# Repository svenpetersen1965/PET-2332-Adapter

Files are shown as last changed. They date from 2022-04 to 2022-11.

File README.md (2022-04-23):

# PET-2332-Adapter
An EPROM adapter for the 2332 sockets in the Commodore (dynamic) PET and 40xx/80xx.

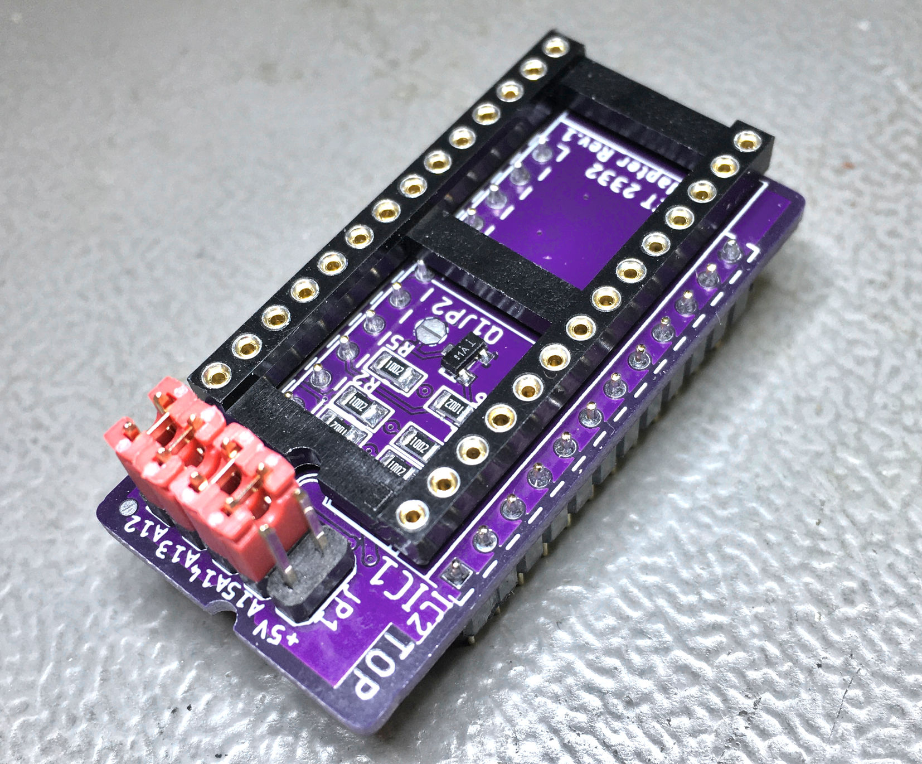
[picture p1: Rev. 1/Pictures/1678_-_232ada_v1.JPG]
2332 Adapter


# Compatibility
* CBM80xx: The adapter is compatible with all ROM sockets (UD6-UD12), except the Character ROM (UA3).
* CBM40xx: The adapter is compatible with all ROM sockets (UD6-UD12), except the Character ROM (UA3).

The CBM30xx are PET2001N-16 or -32 (label in the back).

* PET2001N: The adapter is compatible with all 4k ROM sockets (UD3-UD7 & UD9), <b>except</b> the Edit ROM (UD8) and the Character ROM (UF10). 

This adapter is <b>not suitable</b> for the character generator ROM in any machine (neither C64, nor VIC-20).

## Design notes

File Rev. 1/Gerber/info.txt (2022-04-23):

      
       Board: 2332_adapter_PET
       Rev.:  1
  
       Files:
       ======
  
       All Gerber files are generated in extended gerber format (RS274X)
       *.TOP        : Film top copper
       *.BOT        :  -"- bottom copper
       *.STC        :  -"- top soldermask 
       *.STS        :  -"- bottom soldermask
       *.PLC        :  -"- silk screen top
       *.PLS        :  -"- silk screen bottom
       *.CRC        :  -"- cream top
       *.DK         : Drills plated Through (Excellon)
       *.NDK        : Drills not plated Through (Excellon)
       *.OUT        : Board outline

       Board Size:
       ===========
       Length     :   45.0 mm
       Width      :   22.0 mm
       Thickness  :   1.6 mm
       Material   :   FR 4
       Copper     :   35 um
       Surface    :   HASL
       
       Remarks:
       ========
       minimum drill: 0.35mm
       minimum width: 8 mil
       minimum distance: 6 mil

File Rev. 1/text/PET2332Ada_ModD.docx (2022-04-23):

PET 2332 Adapter Rev. 1

Module Description

This is an adapter board for 27C64 to 27C512 EPROMs for 2332 sockets in PET/CBM machines, that make use of two chip select signals.

2332 Pin | Name
20
21 | CS2

Table 1: Chip selects

Pin 20 is an active low chip select, while Pin 21 is active high. In the CBM8032, is the “normal” chip select, while CS2 is connected to the signal, which switches off all ROMs (except the character ROM) while LOW. Hardware debugging with the diagnostic clip makes use of this feature. In the (dynamic) PET2001N boards, Pin 21 is permanently connected to +5V.

To implement this second chip select, the (active low enable) Pin 20 of the EPROM is utilized as a second chip select. A transistor and a pull-up resistor are used as an inverter for active high CS2 signal.

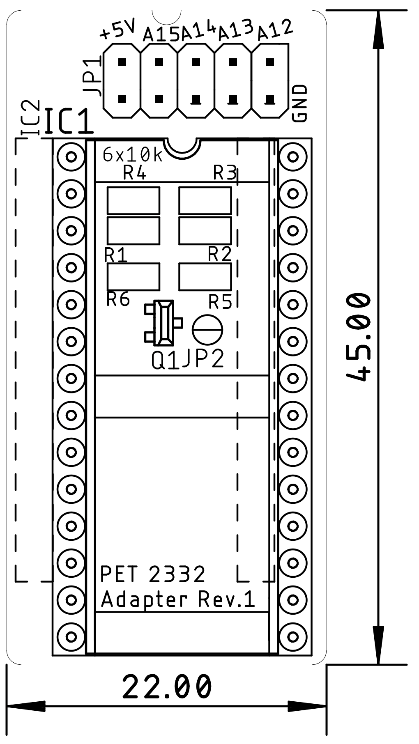
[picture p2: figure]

Figure 1: Dimensions of the PET 2332 Adapter

For a 27C512, up to 16 4k-memory banks can be selected. This is done at the pin header. For a fix setting, the pin header can stay not assembled, since the footprint is suitable for solder bridge configuration.

Signal | Pin | Pin | Signal
A12 | 1 | 2 | GND
A13 | 3 | 4 | GND
A14 | 5 | 6 | GND
A15 | 7 | 8 | GND
+5V | 9 | 10 | n.c.

Table 2: Jumper (JP1) for Bank Selection

The +5V pins are to provide supply voltage to a microcontroller, like the Arduino, in case it is desired to do an automatic bank switching in some way.

# Compatibility

CBM80xx: The adapter is compatible with all ROM sockets (UD6-UD12), except the Character ROM (UA3).

CBM40xx: The adapter is compatible with all ROM sockets (UD6-UD12), except the Character ROM (UA3).

The CBM30xx are PET2001N-16 or -32 (label in the back).

PET2001N: The adapter is compatible with all 4k ROM sockets (UD3-UD7 & UD9), except the Edit ROM (UD8) and the Character ROM (UF10).

# Bank Selection

The desired 4k memory bank is selected at JP1. For the pinout refer to Table 2. The jumper is installed (vertically) in a way, that it connects the address line with the GND potential.

A15 | A14 | A13 | A12 | 4k Block | | Addr. Offset
set | set | set | set | | #0 | 0x0000
set | set | set | open | | #1 | 0x1000
set | set | open | set | | #2 | 0x2000
set | set | open | open | | #3 | 0x3000
set | open | set | set | | #4 | 0x4000
set | open | set | open | | #5 | 0x5000
set | open | open | set | | #6 | 0x6000
set | open | open | open | | #7 | 0x7000
open | set | set | set | | #8 | 0x8000
open | set | set | open | | #9 | 0x9000
open | set | open | set | | #10 | 0xA000
open | set | open | open | | #11 | 0xB000
open | open | set | set | | #12 | 0xC000
open | open | set | open | | #13 | 0xD000
open | open | open | set | | #14 | 0xE000
open | open | open | open | | #15 | 0xF000

Table 3: Selection of EPROM memory blocks

A set jumper corresponds to a LOW level (binary 0), an open jumper to a HIGH level. Do not confuse the PET memory address and the EPROM memory address. They have the address Bit A0 to A11 in common, but the rest is different. The selected memory bank appears in the address of the used socket.

# Compatibility of EPROMs

Although a 27C512 type EPROM is recommended, other types of EPROMs can be installed:

EPROM | Size | Capacity
27C64 | 8k | 2x 4k option ROM
27C128 | 16k | 4x 4k option ROM
27C256 | 32k | 8x 4k option ROM
27C512 | 64k | 16x 4k option ROM

Table 4: Capacity of EPROM types

Those EPROMs are pin compatible, the jumpers, that have no function, due to the size, have to stay open.

EPROM | Size | A15 | A14 | A13 | A12
27C512 | 64kx8 | ☑ | ☑ | ☑ | ☑
27C256 | 32kx8 | open | ☑ | ☑ | ☑
27C128 | 16kx8 | open | open | ☑ | ☑
27C64 | 8kx8 | open | open | open | ☑

Table 5: Settings per EPROM type

☑: The jumper can be open or closed, depending on the desired selection.

In case Vpp is located at a dedicated pin (pin 1), A15 has no effect anymore. A HIGH level is recommended, the corresponding jumper is open. The /PGM Pin should be set HIGH, this is accomplished by an open jumper for A14.

27C64
| 27C128
| | 27C256
| | | 27C512
| | | | SOCKET
Vpp | Vpp | Vpp | A15 | 1 | A15 | VCC | 28 | VCC | VCC | VCC | VCC
A12 | A12 | A12 | A12 | 2 | A12 | A14 | 27 | A14 | A14 | /PGM | /PGM
A7 | A7 | A7 | A7 | 3 | A7 | A13 | 26 | A13 | A13 | A13 | n.c.
A6 | A6 | A6 | A6 | 4 | A6 | A8 | 25 | A8 | A8 | A8 | A8
A5 | A5 | A5 | A5 | 5 | A5 | A9 | 24 | A9 | A9 | A9 | A9
A4 | A4 | A4 | A4 | 6 | A4 | A11 | 23 | A11 | A11 | A11 | A11
A3 | A3 | A3 | A3 | 7 | A3 | /OE | 22 | /G/Vpp | /G | /G | /G
A2 | A2 | A2 | A2 | 8 | A2 | A10 | 21 | A10 | A10 | A10 | A10
A1 | A1 | A1 | A1 | 9 | A1 | GND | 20 | /E | /E | /E | /E
A0 | A0 | A0 | A0 | 10 | A0 | D7 | 19 | D7 | D7 | D7 | D7
D0 | D0 | D0 | D0 | 11 | D0 | D6 | 18 | D6 | D6 | D6 | D6
D1 | D1 | D1 | D1 | 12 | D1 | D5 | 17 | D5 | D5 | D5 | D5
D2 | D2 | D2 | D2 | 13 | D2 | D4 | 16 | D4 | D4 | D4 | D4
GND | GND | GND | GND | 14 | GND | D3 | 15 | D3 | D3 | D3 | D3

Table 6: EPROM pin compatibility

# Using parallel EEPROMs

There are parallel EPROMs, which fit into the EPROM sockets. They do not require erasing with a UV eraser, like EPROMs, but the price is higher.

Since they can be written, which is controlled by the signal, but the Super Expander II cartridge is lacking of this functionality, this signal has to be HIGH (inactive). The 28C256 has the A14 signal connected to Pin 1, which is A15 of the EEPROM socket. This is no problem, but it has to be kept in mind, that the jumper for A15 has effect on the bank select A14 of the EPROM.

28C64
| 28C256
| | SOCKET
n.c. | A14 | 1 | A15 | VCC | 28 | VCC | VCC
A12 | A12 | 2 | A12 | A14 | 27 | /WE | /WE
A7 | A7 | 3 | A7 | A13 | 26 | A13 | n.c
A6 | A6 | 4 | A6 | A8 | 25 | A8 | A8
A5 | A5 | 5 | A5 | A9 | 24 | A9 | A9
A4 | A4 | 6 | A4 | A11 | 23 | A11 | A11
A3 | A3 | 7 | A3 | /OE | 22 | /G/Vpp | /OE
A2 | A2 | 8 | A2 | A10 | 21 | A10 | A10
A1 | A1 | 9 | A1 | GND | 20 | /E | /CE
A0 | A0 | 10 | A0 | D7 | 19 | D7 | D7
D0 | D0 | 11 | D0 | D6 | 18 | D6 | D6
D1 | D1 | 12 | D1 | D5 | 17 | D5 | D5
D2 | D2 | 13 | D2 | D4 | 16 | D4 | D4
GND | GND | 14 | GND | D3 | 15 | D3 | D3

Table 7: EEPROM pin compatibility

EEPROM | Size | A15 | A14 | A13 | A12
28C256 | 32kx8 | =A14 | OPEN | yes | yes
28C64 | 8kx8 | OPEN | OPEN | OPEN | yes

Table 8: Settings per EEPROM type

# Programming instructions

For instructions on setting up a complete multiple character ROM image, please refer to

https://github.com/svenpetersen1965/C64-Kernal-Adapter-Switch-Long-Board/blob/master/Rev.%200/pdf/C64_KernalSw_8k_v0.pdf

The description is about how to create a multiple Kernal ROM image, a multiple 2332 ROM image works pretty similar, except the size is only 4kB.

# Revision History

## Rev. 0

- Prototype, fully functional.

## Rev. 1

- Some experimental features removed.
- Rounded corners and a notch added to identify the orientation
- Fully functional

PET2332Ada_ModD.docx 23.04.2022 15:11 Drafted by Sven Petersen Page 2 of 2 Doc.-No.: 158-6-01-01

PET2332Ada_ModD.docx 23.04.2022 15:11 Drafted by Sven Petersen Page 1 of 1 Doc.-No.: 000-6-00-00

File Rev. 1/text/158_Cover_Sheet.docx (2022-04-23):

Project Documentation

Commodore PET 2332 Adapter

Project number: 158

Revision: 1

Date: 06.03.2022


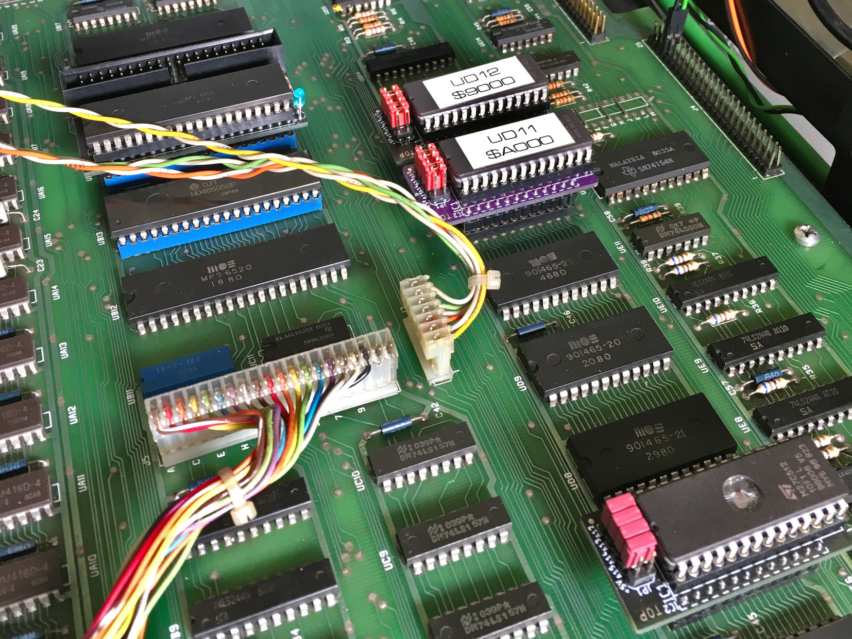
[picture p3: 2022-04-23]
Rev. 1/Pictures/1679_-_2332ada_8032.JPG

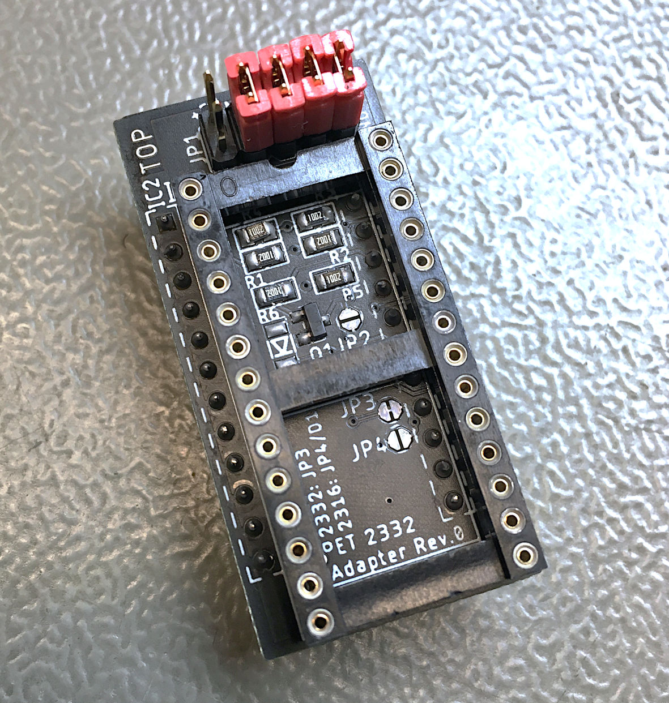
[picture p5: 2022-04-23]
Rev. 1/Pictures/9933_-_2332ada_wo.JPG

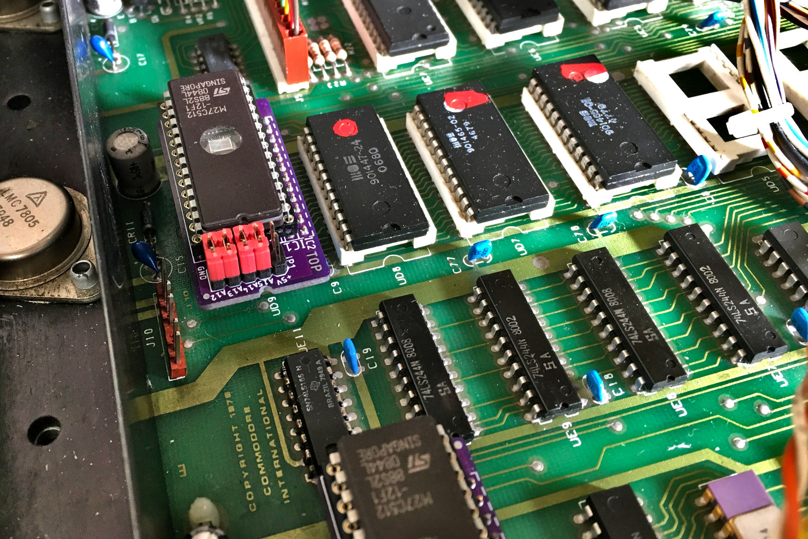
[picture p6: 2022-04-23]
Rev. 1/Pictures/1680_-_2332ada_3016.JPG

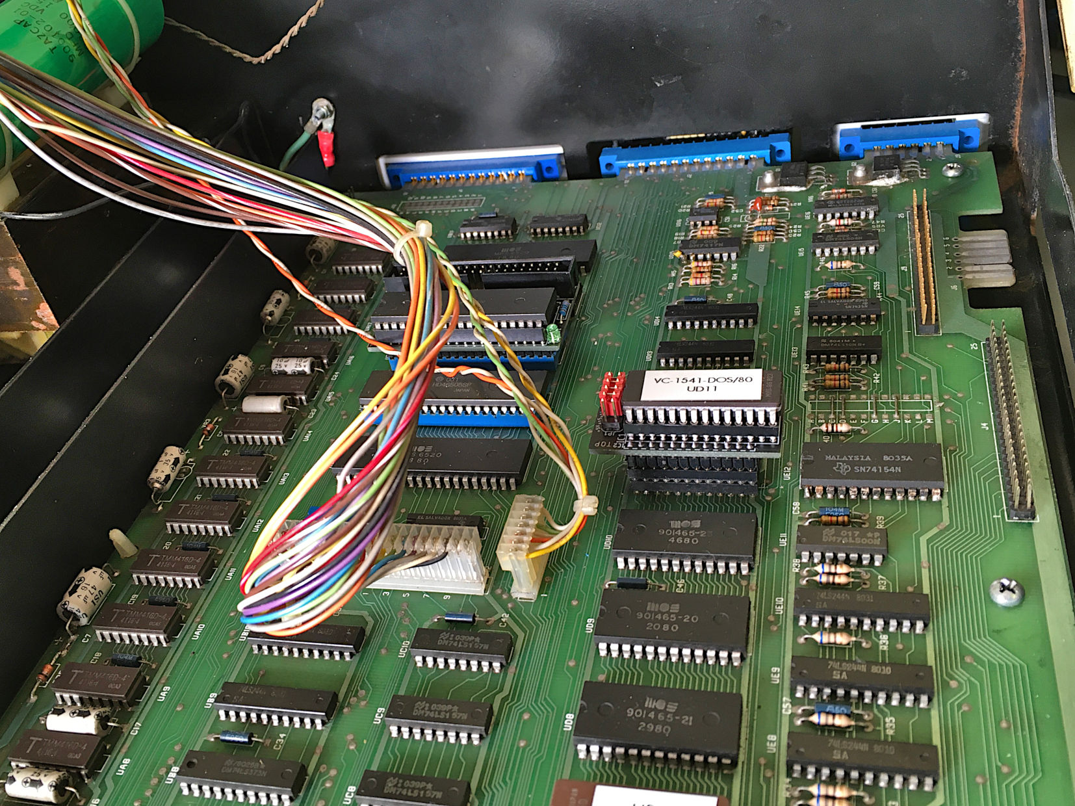
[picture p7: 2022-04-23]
Rev. 1/Pictures/9934_-_2332Ada_in_situ.JPG

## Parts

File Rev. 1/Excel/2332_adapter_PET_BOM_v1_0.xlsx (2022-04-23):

PET/CBM 2332 Adapter Rev. 1
Bill of Material Rev. 1.0
Pos. | Qty | Value | Footprint | Ref.-No. | Comment
1 | 1 | 158-2-01-01 | 2 Layer | PCB Rev. 2 | 2 layer, Cu 35µ, HASL, 45mm x 22mm, 1.6mm FR4
2 | 1 | 2x05pin, 2.54mm | 2X05 | JP1 | Standard pin header, 2.54mm pitch. E.g. Reichelt MPE 087-2-010
3 | 4 | Jumper | 2.54mm | (JP1) | Jumpers for address selection (in case it is intended to jumper the kenal selection)
4 | 6 | 10k | 0805 | R1, R2, R3, R4, R5, R6 | SMD resistor
5 | 1 | two Pinstrip, precision round pins, cut to 12 pins length | DIL24_SOCKET | IC2 | Precision Round pins mandatory! E.g. Reichelt BKL 10120540 or
 |  |  |  |  | 10PCS Single Row 40Pin 2.54mm Round Male Pin Header machined (https://www.ebay.de/itm/10PCS-Single-Row-40Pin-2-54mm-Round-Male-Pin-Header-machined/281821698031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)
6 | 1 | M27C512 | DIL28-6 | IC1 | EPROM 200ns or faster recommended, alternative sizes: 27C64, 27C128, 27C256 possible
7 | 1 | DIP28 socket | DIL28-6 | (IC1) | Precision round pin is recommended
8 | 1 | BC846B | SOT23 | Q1 | npn transistor (BC847, 848 and 849 also suitable)

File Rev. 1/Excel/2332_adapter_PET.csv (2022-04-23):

Qty | Value | Device | Package | Parts | Description
1 |  | OPEN | CP_OP | JP2 | open Cutpad
6 | 10k | R-0805 | 0805 | R1, R2, R3, R4, R5, R6
1 | 2332 | 2332 | DIL24_SOCKET | IC2
1 | BC846B | BC846 | SOT23 | Q1
1 | COMBI-5X2P | COMBI-5X2P | COMBI-5X2 | JP1
1 | M27C512-DIP28 | M27C512-DIP28 | DIL28-6 | IC1
1 | OPEN_SOURCE_HW | OPEN_SOURCE_HW | OPENHW | U$6

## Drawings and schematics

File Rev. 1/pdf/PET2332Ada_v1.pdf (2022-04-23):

# Project Documentation

## Commodore PET 2332 Adapter

## Project number: 158

## Revision: 1

## Date: 06.03.2022

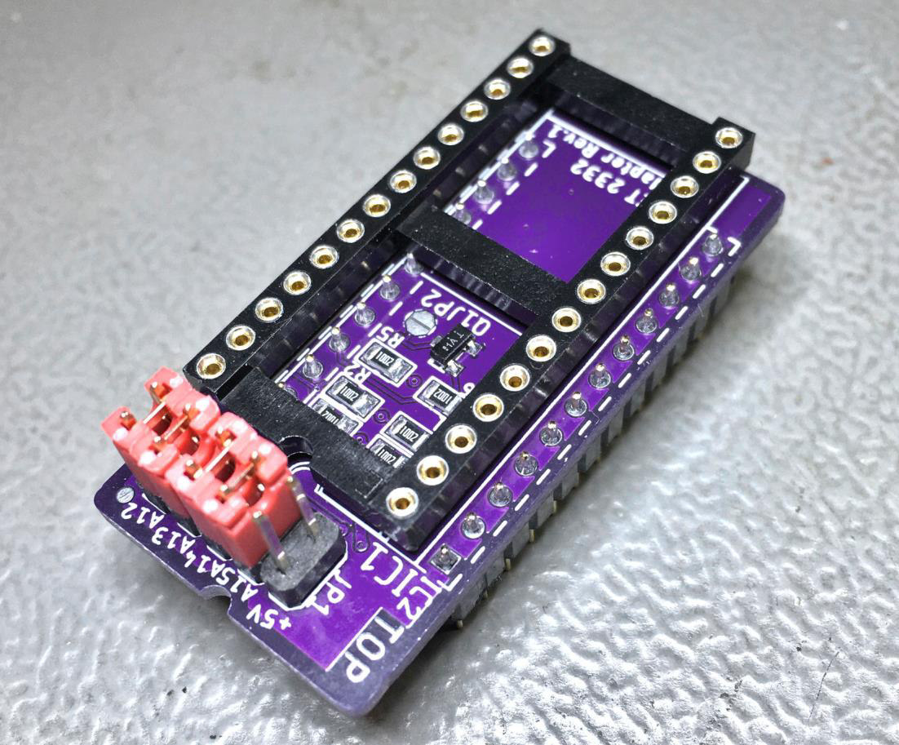
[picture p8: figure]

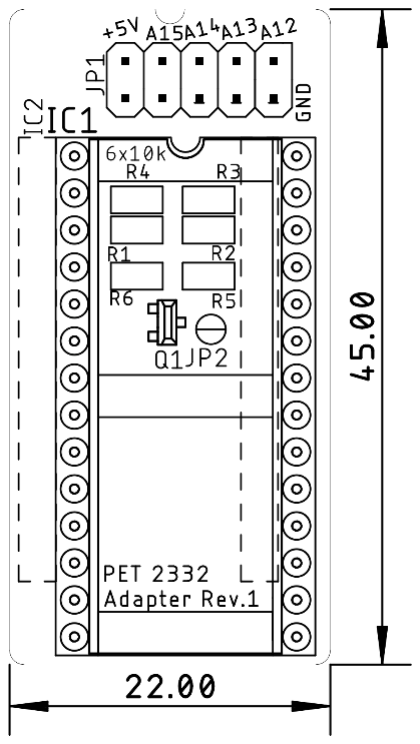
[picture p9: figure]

PET2332Ada_ModD.docx | | 23.04.2022 15:11
Drafted by Sven Petersen | Page 1 of 4 | Doc.-No.: 158-6-01-01

### PET 2332 Adapter Rev. 1

### Module Description

This is an adapter board for 27C64 to 27C512 EPROMs for 2332 sockets in PET/CBM machines, that make use of two chip select signals.

2332 Pin Name
20 CS1

21 CS2
Table 1: Chip selects

Pin 20 is an active low chip select, while Pin 21 is active high. In the CBM8032, CS1 is the

### “normal” chip select, while CS2 is connected to the NOROM signal, which switches off all

ROMs (except the character ROM) while LOW. Hardware debugging with the diagnostic clip makes use of this feature. In the (dynamic) PET2001N boards, Pin 21 is permanently connected to +5V.

To implement this second chip select, the E (active low enable) Pin 20 of the EPROM is utilized as a second chip select. A transistor and a pull-up resistor are used as an inverter for active high CS2 signal.

Figure 1: Dimensions of the PET 2332 Adapter

For a 27C512, up to 16 4k-memory banks can be selected. This is done at the pin header. For a fix setting, the pin header can stay not assembled, since the footprint is suitable for solder bridge configuration.

PET2332Ada_ModD.docx | | 23.04.2022 15:11
Drafted by Sven Petersen | Page 2 of 4 | Doc.-No.: 158-6-01-01
Signal Pin | Pin Signal
A12 | 1 | 2 | GND
A13 | 3 | 4 | GND
A14 | 5 | 6 | GND
A15 | 7 | 8 | GND
+5V | 9 | 10 | n.c.
Table 2: Jumper (JP1) for Bank Selection

The +5V pins are to provide supply voltage to a microcontroller, like the Arduino, in case it is desired to do an automatic bank switching in some way.

## Compatibility

CBM80xx: The adapter is compatible with all ROM sockets (UD6-UD12), except the Character ROM (UA3).

CBM40xx: The adapter is compatible with all ROM sockets (UD6-UD12), except the Character ROM (UA3).

The CBM30xx are PET2001N-16 or -32 (label in the back).

PET2001N: The adapter is compatible with all 4k ROM sockets (UD3-UD7 & UD9), except the Edit ROM (UD8) and the Character ROM (UF10).

## Bank Selection

The desired 4k memory bank is selected at JP1. For the pinout refer to Table 2. The jumper is installed (vertically) in a way, that it connects the address line with the GND potential.

A15 | A14 | A13 | A12 | 4k Block | Addr. Offset
set | set | set | set | #0 | 0x0000
set | set | set | open | #1 | 0x1000
set | set | open | set | #2 | 0x2000
set | set | open | open | #3 | 0x3000
set | open | set | set | #4 | 0x4000
set | open | set | open | #5 | 0x5000
set | open | open | set | #6 | 0x6000
set | open | open | open | #7 | 0x7000
open | set | set | set | #8 | 0x8000
open | set | set | open | #9 | 0x9000
open | set | open | set | #10 | 0xA000
open | set | open | open | #11 | 0xB000
open | open | set | set | #12 | 0xC000
open | open | set | open | #13 | 0xD000
open | open | open | set | #14 | 0xE000
open | open | open | open | #15 | 0xF000
Table 3: Selection of EPROM memory blocks

A set jumper corresponds to a LOW level (binary 0), an open jumper to a HIGH level. Do not confuse the PET memory address and the EPROM memory address. They have the address Bit A0 to A11 in common, but the rest is different. The selected memory bank appears in the address of the used socket.

PET2332Ada_ModD.docx | | 23.04.2022 15:11
Drafted by Sven Petersen | Page 3 of 4 | Doc.-No.: 158-6-01-01
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

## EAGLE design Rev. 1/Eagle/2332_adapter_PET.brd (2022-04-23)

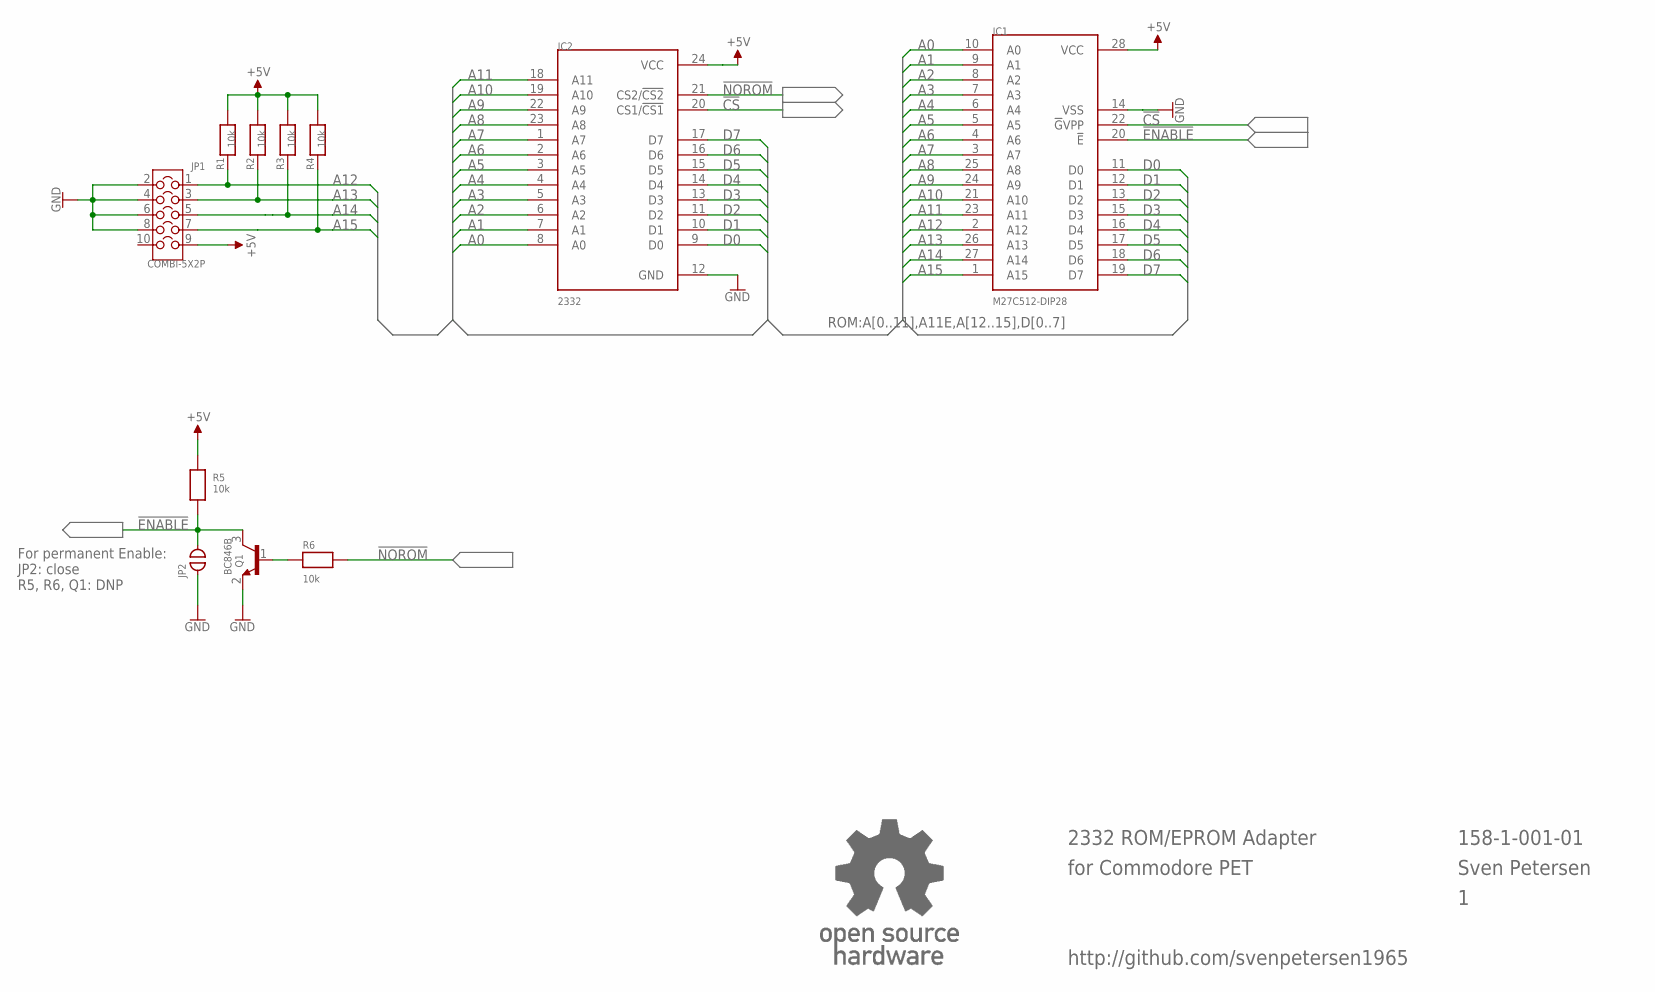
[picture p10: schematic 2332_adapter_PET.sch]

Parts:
IC1: M27C512-DIP28; DIL28-6
IC2: 2332; DIL24_SOCKET
JP1: COMBI-5X2P; COMBI-5X2
JP2: OPEN; CP_OP
Q1: BC846B; SOT23
R1, R2, R3, R4, R5, R6: 10k; 0805
U$6: OPEN_SOURCE_HW; OPENHW

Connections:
!CS: IC1.22 (!G!VPP), IC2.20 (CS1/!CS1)
!ENABLE: IC1.20 (!E), JP2.2, Q1.3 (C), R5.1
!NOROM: IC2.21 (CS2/!CS2), R6.2
+5V: IC1.28 (VCC), IC2.24 (VCC), JP1.9, R1.2, R2.2, R3.2, R4.2, R5.2
A0: IC1.10 (A0), IC2.8 (A0)
A1: IC1.9 (A1), IC2.7 (A1)
A2: IC1.8 (A2), IC2.6 (A2)
A3: IC1.7 (A3), IC2.5 (A3)
A4: IC1.6 (A4), IC2.4 (A4)
A5: IC1.5 (A5), IC2.3 (A5)
A6: IC1.4 (A6), IC2.2 (A6)
A7: IC1.3 (A7), IC2.1 (A7)
A8: IC1.25 (A8), IC2.23 (A8)
A9: IC1.24 (A9), IC2.22 (A9)
A10: IC1.21 (A10), IC2.19 (A10)
A11: IC1.23 (A11), IC2.18 (A11)
A12: IC1.2 (A12), JP1.1, R1.1
A13: IC1.26 (A13), JP1.3, R2.1
A14: IC1.27 (A14), JP1.5, R3.1
A15: IC1.1 (A15), JP1.7, R4.1
D0: IC1.11 (D0), IC2.9 (D0)
D1: IC1.12 (D1), IC2.10 (D1)
D2: IC1.13 (D2), IC2.11 (D2)
D3: IC1.15 (D3), IC2.13 (D3)
D4: IC1.16 (D4), IC2.14 (D4)
D5: IC1.17 (D5), IC2.15 (D5)
D6: IC1.18 (D6), IC2.16 (D6)
D7: IC1.19 (D7), IC2.17 (D7)
GND: IC1.14 (VSS), IC2.12 (GND), JP1.2, JP1.4, JP1.6, JP1.8, JP2.1, Q1.2 (E)
unnamed: Q1.1 (B), R6.1

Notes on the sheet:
158-1-001-01
Sven Petersen
http://github.com/svenpetersen1965
For permanent Enable: JP2: close R5, R6, Q1: DNP
2332 ROM/EPROM Adapter
for Commodore PET

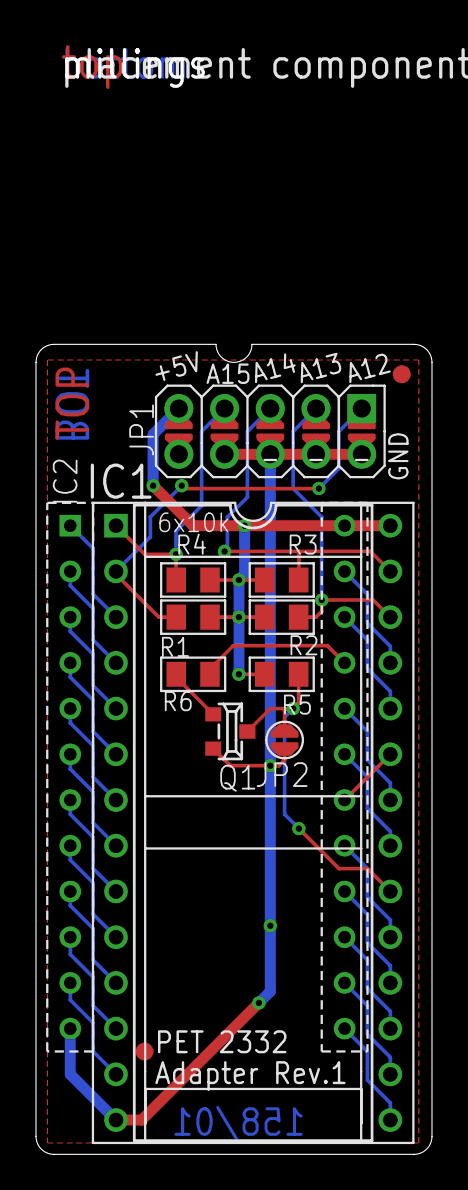
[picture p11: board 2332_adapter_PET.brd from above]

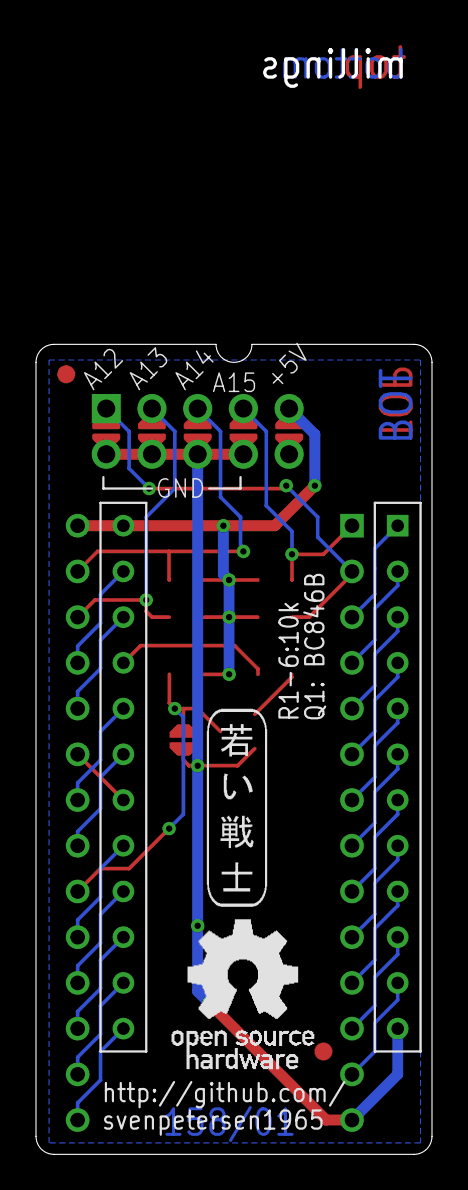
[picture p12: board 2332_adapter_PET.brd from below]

Board: 2 copper layers, 22.0 x 45.0 mm, 18 parts (2 on the bottom side), 30 nets.

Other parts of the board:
U$11: SVEN_TAG
U$16: GS28P
U$17, U$18: SMD_REF_R1MM
U$19: 2LAYER
U$20: PCB-TITLE/

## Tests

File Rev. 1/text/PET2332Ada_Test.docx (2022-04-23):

PET 2332 Adapter Rev. 1

Testing

# 1. Test Setup

1. PET 2332 Adapter Rev. 0
2. PET 2332 Adapter Rev. 1
3. CBM8032 (Mainboard ASSY8032030, with CRTC)
4. CBM3016 (Mainboard ASSY320351 Rev. E, without CRTC)
5. A variety of 27C512 EPROMs (120ns)
6. Diagnostic Clip (for CBM80xx)

# 2. Test Execution

## 2.1. Option ROM in the CBM8032

The Adapter was used for UD11 and UD12 in the CBM8032. The used software was

- VC1541DOS/80 (UD11)
- SM-Kit-B 2.3 (UD12)
- SM-Kit-M 2.3 (UD11)
- EXBASIC V8.1 (UD12/UD11)

The software was installed in different ROM banks on the 27C512. Both Revision Rev. 0 and Rev. 1 were tested.


Figure 1: The 2332 adapter in UD11 (v1), UD12 and UD7 (both v0)

Also, the diagnostic clip, which males use of the active HIGH chip select pin CS2 (with the /NOROM signal) is working in conjunction with the adapters.

The adapter and EPROMs worked flawless.

## 2.2. Edit ROM in the CBM8032

The software found in the CBM8032, which was used for the test was programmed into a 27C512 and used in the Edit ROM socket UD7.

The computer worked flawless with this configuration.

## 2.3. Kernal ROM in the CBM3016/Dynamic PET2001N-16

The Kernal 901465-03 (BASIC 2) was programmed into a 27C512, inserted into the 2332 adapter Rev. 1 and installed in the socket UD9 for the Kernal.


Figure 2: The 2332 adapter v1 in UD9 (Kernal)

The computer worked flawless with this configuration.

# 3. Conclusion

The 2332 adapters (Rev. 0 and Rev. 1) are fully functional.

PET2332Ada_Test.docx 23.04.2022 15:09 Drafted by Sven Petersen Page 2 of 2 Doc.-No.: 158-6-02-01

PET2332Ada_Test.docx 23.04.2022 15:09 Drafted by Sven Petersen Page 1 of 1 Doc.-No.: 000-6-00-00
